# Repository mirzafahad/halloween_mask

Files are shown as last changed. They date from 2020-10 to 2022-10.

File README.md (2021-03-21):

# Halloween Mask



:star: Star me on GitHub — it helps!

Added the famous [Uncanny Eyes](https://learn.adafruit.com/animated-electronic-eyes) to a Mask. The PCB has three connectors for sensors:
- PIR conenctor
- I2C connector for any I2C capabale sensor
- LDR 

If you don't need want to use EL wire you can use the EL wire conenctor for other sensors, motors, relays etc.

Components used:
- [Adafruit ItsyBitsy M0](https://www.adafruit.com/product/3727)
- 2 x 1.44" [TFT Display](https://tinyurl.com/y4xz52jo)
- [Mask](https://tinyurl.com/y5uo26v6)
- [LDR](https://www.adafruit.com/product/161) 

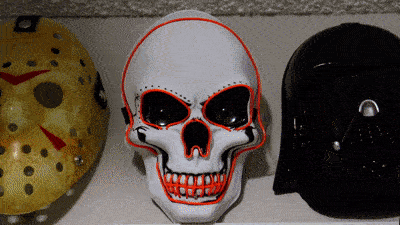
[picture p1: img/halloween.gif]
Mask in action


More info: https://mirzafahad.github.io/2020-10-31-halloween-mask/

Youtube: https://youtu.be/H35RDPNnSZM

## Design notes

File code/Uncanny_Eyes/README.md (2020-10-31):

# Fahad Mirza

Made necessary changes to according to my circuit.

# Uncanny_Eyes

'Uncanny eyes' for Adafruit 1.5" OLED (product #1431) or 1.44" TFT LCD (#2088).  Works on PJRC Teensy 3.x and on Adafruit M0 and M4 boards (Feather, Metro, etc.).  This code uses features specific to these boards and WILL NOT work on normal Arduino or other boards!

How-to guide with parts list and 3D models is here:
https://learn.adafruit.com/animated-electronic-eyes-using-teensy-3-1/overview

Teensy 3.x w/OLED screens: use 72 MHz board speed -- 96 MHz requires throttling back SPI bitrate and actually runs slower!

Directory 'uncannyEyes' contains Arduino sketch for PJRC Teensy 3.1 & Adafruit M0 & M4. 'graphics' subfolder has various eye designs, as #include-able header files.

Folder 'convert' contains Python sketch for generating graphics header files. Requires Python Imaging Library. Example images are also in this directory.

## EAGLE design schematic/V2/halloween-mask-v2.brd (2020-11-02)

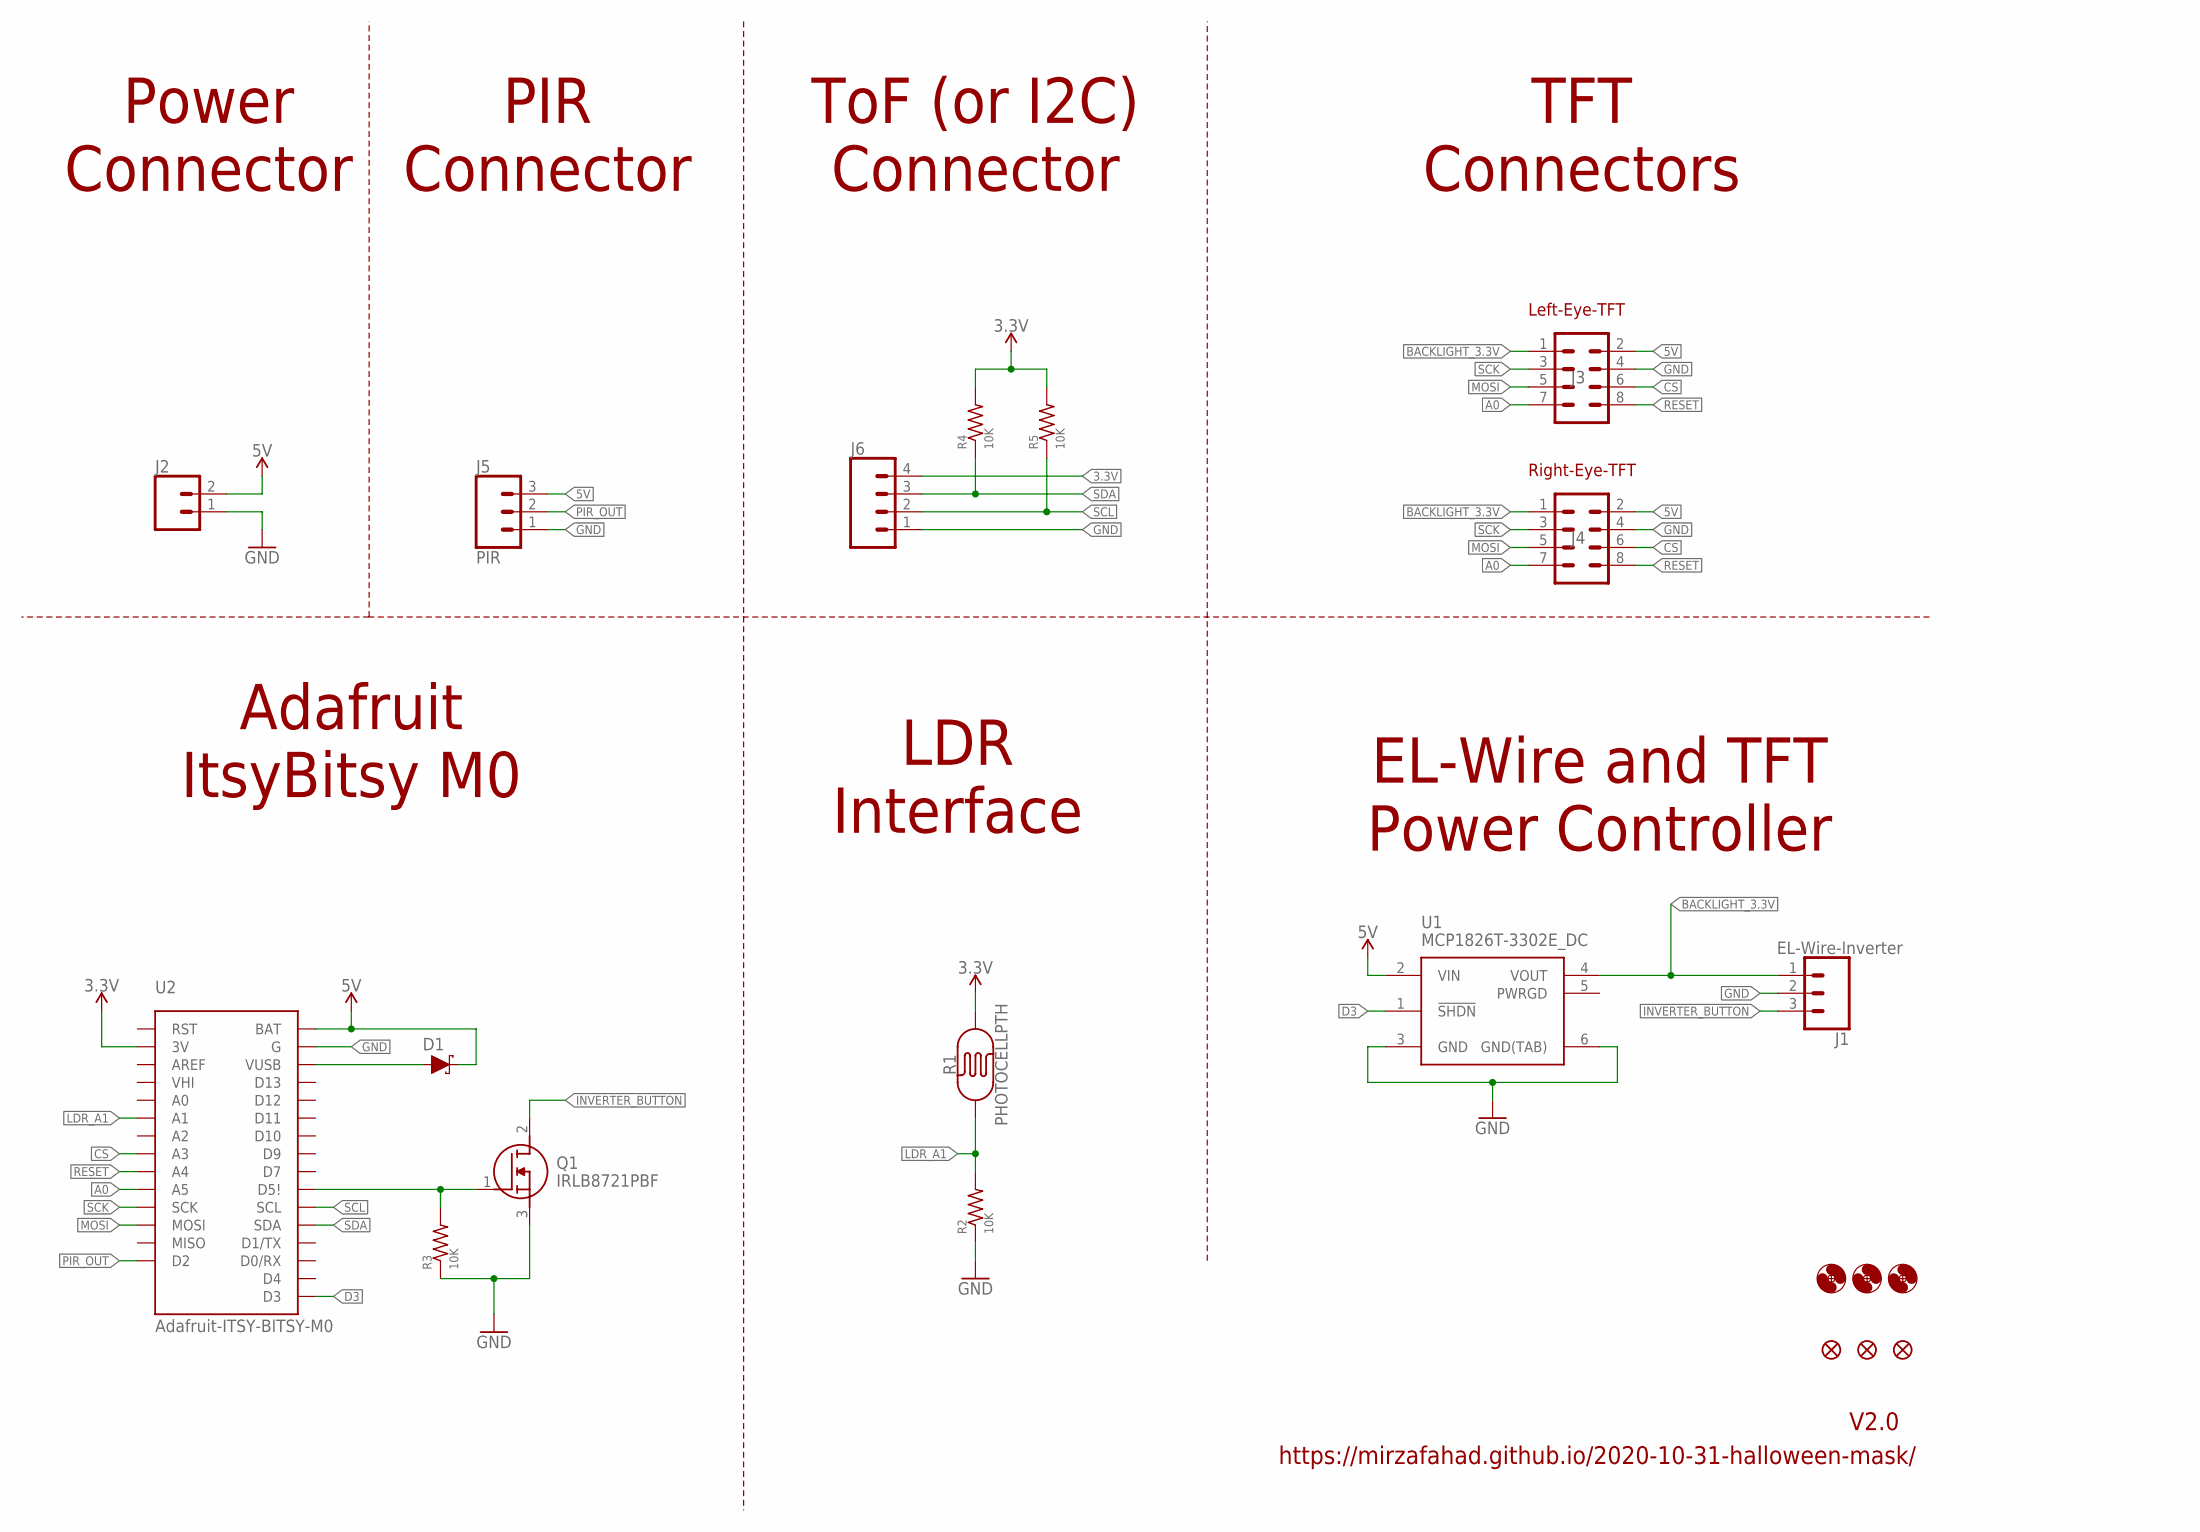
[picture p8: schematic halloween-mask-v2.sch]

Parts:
D1: DIODE-SCHOTTKY-MBR130T1G; SOD-123
FD1, FD2, FD3: FIDUCIAL0.2MM; FIDUCIAL-0.2MM
H1, H2, H4: MOUNT-HOLE2.8; 2,8
J1: EL-Wire-Inverter; 1X03
J2: CONN_02LOCK; 1X02_LOCK
J3, J4: CONN_04X2; 2X4
J5: PIR; 1X03_LOCK
J6: CONN_04PTH; 1X04
Q1: IRLB8721PBF; TO254P483X1016X1994-3P
R1: PHOTOCELLPTH; PHOTOCELL
R2, R3, R4, R5: 10K; R1206
U1: MCP1826T-3302E_DC; SOT127P706X180-6N
U2: Adafruit-ITSY-BITSY-M0; ITSY-BITSY-LESS-PINS

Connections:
3.3V: J6.4, R1.2, R4.2, R5.2, U2.P2 (3V)
5V: D1.2 (C), J2.2, J3.2, J4.2, J5.3, U1.2 (VIN), U2.P28 (BAT)
A0: J3.7, J4.7, U2.P10 (A5)
BACKLIGHT_3.3V: J1.1, J3.1, J4.1, U1.4 (VOUT)
CS: J3.6, J4.6, U2.P8 (A3)
D3: U1.1 (!SHDN), U2.18 (D3)
GND: J1.2, J2.1, J3.4, J4.4, J5.1, J6.1, Q1.3 (S), R2.1, R3.1, U1.3 (GND), U1.6 (GND(TAB)), U2.P27 (G)
INVERTER_BUTTON: J1.3, Q1.2 (D)
LDR_A1: R1.1, R2.2, U2.P6 (A1)
MOSI: J3.5, J4.5, U2.P12 (MOSI)
unnamed: D1.1 (A), U2.P26 (VUSB)
unnamed: Q1.1 (G), R3.2, U2.P19 (D5!)
PIR_OUT: J5.2, U2.P14 (D2)
RESET: J3.8, J4.8, U2.P9 (A4)
SCK: J3.3, J4.3, U2.P11 (SCK)
SCL: J6.2, R5.1, U2.P18 (SCL)
SDA: J6.3, R4.1, U2.P17 (SDA)

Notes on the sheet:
V2.0
TFT Connectors
Left-Eye-TFT
Right-Eye-TFT
ToF (or I2C) Connector
EL-Wire and TFT Power Controller
PIR Connector
Power Connector
LDR Interface
Adafruit ItsyBitsy M0
https://mirzafahad.github.io/2020-10-31-halloween-mask/

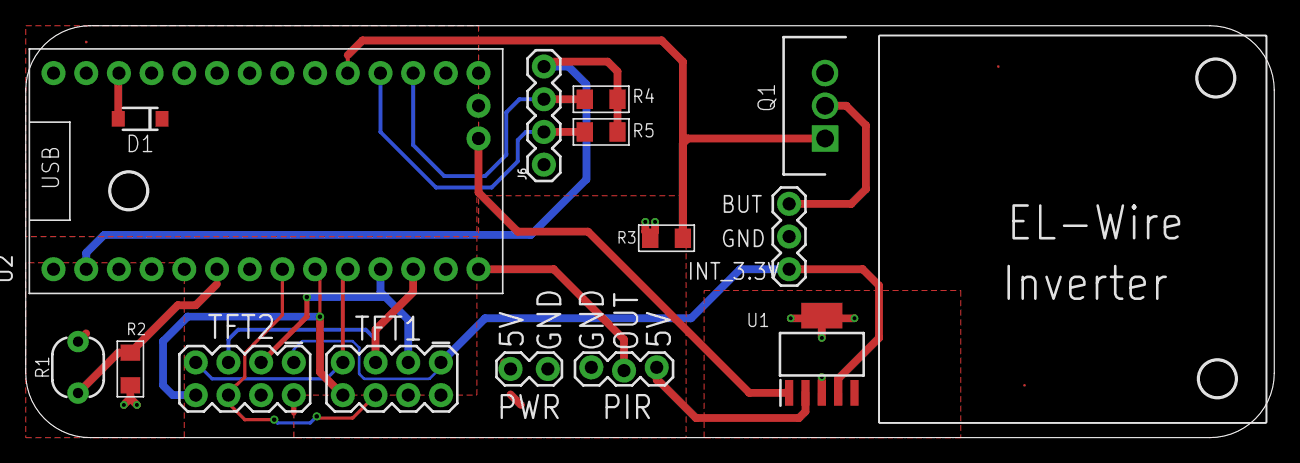
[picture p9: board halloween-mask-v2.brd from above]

Board: 2 copper layers, 97.0 x 32.0 mm, 22 parts (0 on the bottom side), 17 nets.

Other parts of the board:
U$2: ELECTROCAT_LOGO_38X14MM

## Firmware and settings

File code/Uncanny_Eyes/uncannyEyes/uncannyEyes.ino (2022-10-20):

//--------------------------------------------------------------------------
// Uncanny eyes for Adafruit 1.5" OLED (product #1431) or 1.44" TFT LCD
// (#2088).  Works on PJRC Teensy 3.x and on Adafruit M0 and M4 boards
// (Feather, Metro, etc.).  This code uses features specific to these
// boards and WILL NOT work on normal Arduino or other boards!
//
// SEE FILE "config.h" FOR MOST CONFIGURATION (graphics, pins, display type,
// etc).  Probably won't need to edit THIS file unless you're doing some
// extremely custom modifications.
//
// Adafruit invests time and resources providing this open source code,
// please support Adafruit and open-source hardware by purchasing products
// from Adafruit!
//
// Written by Phil Burgess / Paint Your Dragon for Adafruit Industries.
// MIT license.  SPI FIFO insight from Paul Stoffregen's ILI9341_t3 library.
// Inspired by David Boccabella's (Marcwolf) hybrid servo/OLED eye concept.
//--------------------------------------------------------------------------

#include <SPI.h>
#include <Adafruit_GFX.h>
#ifdef ARDUINO_ARCH_SAMD
  #include <Adafruit_ZeroDMA.h>
#endif


typedef struct {        // Struct is defined before including config.h --
  int8_t  select;       // pin numbers for each eye's screen select line
  int8_t  wink;         // and wink button (or -1 if none) specified there,
  uint8_t rotation;     // also display rotation.
} eyeInfo_t;

#include "config.h"     // ****** CONFIGURATION IS DONE IN HERE ******

extern void user_setup(void); // Functions in the user*.cpp files
extern void user_loop(void);

#ifdef PIXEL_DOUBLE
  // For the 240x240 TFT, pixels are rendered in 2x2 blocks for an
  // effective resolution of 120x120. M0 boards just don't have the
  // space or speed to handle an eye at the full resolution of this
  // display (and for M4 boards, take a look at the M4_Eyes project
  // instead). 120x120 doesn't quite match the resolution of the
  // TFT & OLED this project was originally developed for. Rather
  // than make an entirely new alternate set of graphics for every
  // eye (would be a huge undertaking), this currently just crops
  // four pixels all around the perimeter.
  #define SCREEN_X_START 4
  #define SCREEN_X_END   (SCREEN_WIDTH - 4)
  #define SCREEN_Y_START 4
  #define SCREEN_Y_END   (SCREEN_HEIGHT - 4)
#else
  #define SCREEN_X_START 0
  #define SCREEN_X_END   SCREEN_WIDTH
  #define SCREEN_Y_START 0
  #define SCREEN_Y_END   SCREEN_HEIGHT
#endif

#if defined(_ADAFRUIT_ST7789H_)
  typedef Adafruit_ST7789  displayType; // Using 240x240 TFT display(s)
#elif defined(_ADAFRUIT_ST7735H_) || defined(_ADAFRUIT_ST77XXH_)
  //typedef Adafruit_ST7735  displayType; // Using TFT display(s)
  //typedef Adafruit_HX8357  displayType;
  typedef Adafruit_ILI9341 displayType;
#else
  //typedef Adafruit_SSD1351 displayType; // Using OLED display(s)
  //typedef Adafruit_HX8357  displayType;
  typedef Adafruit_ILI9341 displayType;
#endif

// A simple state machine is used to control eye blinks/winks:
#define NOBLINK 0       // Not currently engaged in a blink
#define ENBLINK 1       // Eyelid is currently closing
#define DEBLINK 2       // Eyelid is currently opening
typedef struct 
{
  uint8_t  state;       // NOBLINK/ENBLINK/DEBLINK
  uint32_t duration;    // Duration of blink state (micros)
  uint32_t startTime;   // Time (micros) of last state change
} eyeBlink;

#define NUM_EYES (sizeof eyeInfo / sizeof eyeInfo[0]) // config.h pin list

struct {                // One-per-eye structure
  displayType *display; // -> OLED/TFT object
  eyeBlink     blink;   // Current blink/wink state
} eye[NUM_EYES];

#ifdef ARDUINO_ARCH_SAMD
  // SAMD boards use DMA (Teensy uses SPI FIFO instead):
  // Two single-scanline pixel buffers are used for DMA,
  // alternating rendering and transferring between them.
  // Though you'd think fewer larger transfers would improve speed,
  // multi-line buffering made no appreciable difference.
  uint8_t           dmaIdx = 0; // Active DMA buffer # (alternate fill/send)
  Adafruit_ZeroDMA  dma;
 #ifdef PIXEL_DOUBLE
  uint32_t          dmaBuf[2][120]; // Two 120-pixel buffers (32bit for doubling)
  DmacDescriptor   *descriptor[2];  // Pair of descriptors for doubled scanlines
 #else
  uint16_t          dmaBuf[2][128]; // Two 128-pixel buffers
  DmacDescriptor   *descriptor;     // Single active DMA descriptor
 #endif
  // DMA transfer-in-progress indicator and callback
  static volatile bool dma_busy = false;
  static void dma_callback(Adafruit_ZeroDMA *dma) { dma_busy = false; }
#elif defined(ARDUINO_ARCH_NRF52)
  uint8_t           dmaIdx = 0; // Active DMA buffer # (alternate fill/send)
 #ifdef PIXEL_DOUBLE
  uint32_t          dmaBuf[2][240]; // Two 240-pixel buffers (32bit for doubling)
 #else
  uint16_t          dmaBuf[2][128]; // Two 128-pixel buffers
 #endif
#endif

uint32_t startTime;  // For FPS indicator

#if defined(SYNCPIN) && (SYNCPIN >= 0)
#include <Wire.h>
// If two boards are synchronized over I2C, this struct is passed from one
// to other. No device-independent packing & unpacking is performed...both
// boards are expected to be the same architecture & endianism.
struct {
  uint16_t iScale;  // These are basically the same arguments as
  uint8_t  scleraX; // drawEye() expects, explained in that function.
  uint8_t  scleraY;
  uint8_t  uT;
  uint8_t  lT;
} syncStruct = { 512,
  (SCLERA_WIDTH-SCREEN_WIDTH)/2, (SCLERA_HEIGHT-SCREEN_HEIGHT)/2, 0, 0 };

void wireCallback(int n) {
  if(n == sizeof syncStruct) {
    // Read 'n' bytes from I2C into syncStruct
    uint8_t *ptr = (uint8_t *)&syncStruct;
    for(uint8_t i=0; i < sizeof syncStruct; i++) {
      ptr[i] = Wire.read();
    }
  }
}

bool receiver = false;
#endif // SYNCPIN

// INITIALIZATION -- runs once at startup ----------------------------------

void setup(void) 
{
  uint8_t e; // Eye index, 0 to NUM_EYES-1

#if defined(SYNCPIN) && (SYNCPIN >= 0) // If using I2C sync...
  pinMode(SYNCPIN, INPUT_PULLUP);      // Check for jumper to ground
  if(!digitalRead(SYNCPIN)) {          // If there...
    receiver = true;                   // Set this one up as receiver
    Wire.begin(SYNCADDR);
    Wire.onReceive(wireCallback);
  } else {
    Wire.begin();                      // Else set up as sender
  }
#endif

  Serial.begin(115200);
  //while (!Serial);
  Serial.println("Init");
  randomSeed(analogRead(A0)); // Seed random() from floating analog input

#ifdef DISPLAY_BACKLIGHT
  // Enable backlight pin, initially off
  Serial.println("Backlight off");
  pinMode(DISPLAY_BACKLIGHT, OUTPUT);
  digitalWrite(DISPLAY_BACKLIGHT, LOW);
#endif

  user_setup();

  // Initialize eye objects based on eyeInfo list in config.h:
  for(e=0; e<NUM_EYES; e++) 
  {
    Serial.print("Create display #"); 
    Serial.println(e);
#if defined(_ADAFRUIT_ST7789H_) // 240x240 TFT
    eye[e].display     = new displayType(&TFT_SPI, eyeInfo[e].select, DISPLAY_DC, -1);
#elif defined(_ADAFRUIT_ST7735H_) || defined(_ADAFRUIT_ST77XXH_) // 128x128 TFT
    eye[e].display     = new displayType(&TFT_SPI, eyeInfo[e].select, DISPLAY_DC, -1);
#else // OLED
    //eye[e].display     = new displayType(128, 128, &TFT_SPI, eyeInfo[e].select, DISPLAY_DC, -1);
    // HX8357
    //eye[e].display     = new displayType(&TFT_SPI, eyeInfo[e].select, DISPLAY_DC, DISPLAY_RESET);
    eye[e].display     = new displayType(eyeInfo[e].select, DISPLAY_DC, DISPLAY_RESET);
#endif
    eye[e].blink.state = NOBLINK;
    // If project involves only ONE eye and NO other SPI devices, its
    // select line can be permanently tied to GND and corresponding pin
    // in config.h set to -1.  Best to use it though.
    if(eyeInfo[e].select >= 0) 
    {
      pinMode(eyeInfo[e].select, OUTPUT);
      digitalWrite(eyeInfo[e].select, HIGH); // Deselect them all
    }
    // Also set up an individual eye-wink pin if defined:
    if(eyeInfo[e].wink >= 0) pinMode(eyeInfo[e].wink, INPUT_PULLUP);
  }
#if defined(BLINK_PIN) && (BLINK_PIN >= 0)
  pinMode(BLINK_PIN, INPUT_PULLUP); // Ditto for all-eyes blink pin
#endif

#if defined(DISPLAY_RESET) && (DISPLAY_RESET >= 0)
  // Because both displays share a common reset pin, -1 is passed to
  // the display constructor above to prevent the begin() function from
  // resetting both displays after one is initialized.  Instead, handle
  // the reset manually here to take care of both displays just once:
  Serial.println("Reset displays");
  pinMode(DISPLAY_RESET, OUTPUT);
  digitalWrite(DISPLAY_RESET, LOW);  delay(1);
  digitalWrite(DISPLAY_RESET, HIGH); delay(50);
  // Alternately, all display reset pin(s) could be connected to the
  // microcontroller reset, in which case DISPLAY_RESET should be set
  // to -1 or left undefined in config.h.
#else
  // If no DISPLAY_RESET pin is defined, the board might have an auto-
  // reset circuit for the display (e.g. TFT Gizmo). Pause for just a
  // tiny moment to allow it to work, otherwise commands will be issued
  // too soon and the display won't correctly initialize.
  delay(75);
#endif

  // After all-displays reset, now call init/begin func for each display:
  for(e=0; e<NUM_EYES; e++) {
#if defined(_ADAFRUIT_ST7789H_) // 240x240 TFT
    eye[e].display->init(240, 240);
#elif defined(_ADAFRUIT_ST7735H_) || defined(_ADAFRUIT_ST77XXH_) // 128x128 TFT
    eye[e].display->initR(INITR_144GREENTAB);
    Serial.print("Init ST77xx display #"); Serial.println(e);
#else // OLED
    eye[e].display->begin(SPI_FREQ);
    eye[e].display->fillScreen(ILI9341_BLACK);
#endif
    Serial.println("Rotate");
    eye[e].display->setRotation(eyeInfo[e].rotation);
  }
  Serial.println("done");

#if defined(LOGO_TOP_WIDTH) || defined(COLOR_LOGO_WIDTH)
  // I noticed lots of folks getting right/left eyes flipped, or
  // installing upside-down, etc.  Logo split across screens may help:
  int x = eye[0].display->width() * NUM_EYES / 2;
  int y = (eye[0].display->height() - SCREEN_HEIGHT) / 2;
  for(e=0; e<NUM_EYES; e++) { // Another pass, after all screen inits
    eye[e].display->fillScreen(0);
    #ifdef LOGO_TOP_WIDTH
      // Monochrome Adafruit logo is 2 mono bitmaps:
      eye[e].display->drawBitmap(x - LOGO_TOP_WIDTH / 2 - 20,
        y, logo_top, LOGO_TOP_WIDTH, LOGO_TOP_HEIGHT, 0xFFFF);
      eye[e].display->drawBitmap(x - LOGO_BOTTOM_WIDTH/2,
        y + LOGO_TOP_HEIGHT, logo_bottom, LOGO_BOTTOM_WIDTH, LOGO_BOTTOM_HEIGHT,
        0xFFFF);
    #else
      // Color sponsor logo is one RGB bitmap:
      eye[e].display->fillScreen(color_logo[0]);
      eye[e].display->drawRGBBitmap(
        (eye[e].display->width()  - COLOR_LOGO_WIDTH ) / 2,
        (eye[e].display->height() - COLOR_LOGO_HEIGHT) / 2,
        color_logo, COLOR_LOGO_WIDTH, COLOR_LOGO_HEIGHT);
    #endif
    x -= eye[e].display->width();
  }
  // After logo is drawn
  #ifdef DISPLAY_BACKLIGHT
    int i;
    Serial.println("Fade in backlight");
    analogWriteResolution(8);
    for(i=0; i<=BACKLIGHT_MAX; i++) { // Fade logo in
      analogWrite(DISPLAY_BACKLIGHT, i);
      delay(2);
    }
    delay(1400); // Pause for screen layout/orientation
    Serial.println("Fade out backlight");
    for(; i>=0; i--) {
      analogWrite(DISPLAY_BACKLIGHT, i);
      delay(2);
    }
    for(e=0; e<NUM_EYES; e++) { // Clear display(s)
      eye[e].display->fillScreen(0);
    }
    delay(100);
  #else
    delay(2000); // Pause for screen layout/orientation
  #endif // DISPLAY_BACKLIGHT
#endif // LOGO_TOP_WIDTH

  // One of the displays is configured to mirror on the X axis.  Simplifies
  // eyelid handling in the drawEye() function -- no need for distinct
  // L-to-R or R-to-L inner loops.  Just the X coordinate of the iris is
  // then reversed when drawing this eye, so they move the same.  Magic!
#if defined(SYNCPIN) && (SYNCPIN >= 0)
  if(receiver) {
#endif
#if defined(_ADAFRUIT_ST7789H_) // 240x240 TFT
    // MAYBE TODO: HANDLE 240x240 TFT MIRRORING HERE
#elif defined(_ADAFRUIT_ST7735H_) || defined(_ADAFRUIT_ST77XXH_) // TFT
    const uint8_t mirrorTFT[]  = { 0x88, 0x28, 0x48, 0xE8 }; // Mirror+rotate
    eye[0].display->sendCommand(
    #ifdef ST77XX_MADCTL
      ST77XX_MADCTL, // Current TFT lib
    #else
      ST7735_MADCTL, // Older TFT lib
    #endif
      &mirrorTFT[eyeInfo[0].rotation & 3], 1);
  #else // OLED
//    const uint8_t rotateOLED[] = { 0x74, 0x77, 0x66, 0x65 },
//                  mirrorOLED[] = { 0x76, 0x67, 0x64, 0x75 }; // Mirror+rotate
//    // If OLED, loop through ALL eyes and set up remap register
//    // from either mirrorOLED[] (first eye) or rotateOLED[] (others).
//    // The OLED library doesn't normally use the remap reg (TFT does).
//    for(e=0; e<NUM_EYES; e++) {
//      eye[e].display->sendCommand(SSD1351_CMD_SETREMAP, e ?
//        &rotateOLED[eyeInfo[e].rotation & 3] :
//        &mirrorOLED[eyeInfo[e].rotation & 3], 1);
//}
    const uint8_t mirrorTFT[]  = { 0x88, 0x28, 0x48, 0xE8 }; // Mirror+rotate
    //eye[0].display->sendCommand(HX8357_MADCTL, &mirrorTFT[eyeInfo[0].rotation & 3], 1);
    eye[0].display->sendCommand(ILI9341_MADCTL, &mirrorTFT[eyeInfo[0].rotation & 3], 1);
    
#endif
#if defined(SYNCPIN) && (SYNCPIN >= 0)
  } // Don't mirror receiver screen
#endif

#ifdef ARDUINO_ARCH_SAMD
  // Set up SPI DMA on SAMD boards:
  int                dmac_id  = TFT_SPI.getDMAC_ID_TX();
  volatile uint32_t *data_reg = TFT_SPI.getDataRegister();

  Serial.println("DMA init");
  dma.allocate();
  dma.setTrigger(dmac_id);
  dma.setAction(DMA_TRIGGER_ACTON_BEAT);
#ifdef PIXEL_DOUBLE
  // A chain of 2 linked descriptors point to the same buffer.
  // Poof, doubled scanlines.
  for(uint8_t i=0; i<2; i++) {
    descriptor[i] = dma.addDescriptor(
      NULL,               // move data
      (void *)data_reg,   // to here
      sizeof dmaBuf[0],   // this many...
      DMA_BEAT_SIZE_BYTE, // bytes/hword/words
      true,               // increment source addr?
      false);             // increment dest addr?
  }
#else
  descriptor = dma.addDescriptor(
    NULL,               // move data
    (void *)data_reg,   // to here
    sizeof dmaBuf[0],   // this many...
    DMA_BEAT_SIZE_BYTE, // bytes/hword/words
    true,               // increment source addr?
    false);             // increment dest addr?
#endif
  dma.setCallback(dma_callback);

#endif // End SAMD-specific SPI DMA init

#ifdef DISPLAY_BACKLIGHT
  Serial.println("Backlight on!");
  analogWrite(DISPLAY_BACKLIGHT, BACKLIGHT_MAX);
#endif

  startTime = millis(); // For frame-rate calculation
}


// EYE-RENDERING FUNCTION --------------------------------------------------

SPISettings settings(SPI_FREQ, MSBFIRST, SPI_MODE0);

void drawEye( // Renders one eye.  Inputs must be pre-clipped & valid.
  uint8_t  e,       // Eye array index; 0 or 1 for left/right
  uint16_t iScale,  // Scale factor for iris (0-1023)
  uint8_t  scleraX, // First pixel X offset into sclera image
  uint8_t  scleraY, // First pixel Y offset into sclera image
  uint8_t  uT,      // Upper eyelid threshold value
  uint8_t  lT) {    // Lower eyelid threshold value

  uint8_t  screenX, screenY, scleraXsave;
  int16_t  irisX, irisY;
  uint16_t p, a;
  uint32_t d;

#if defined(SYNCPIN) && (SYNCPIN >= 0)
  if(receiver) {
    // Overwrite arguments with values in syncStruct.  Disable interrupts
    // briefly so new data can't overwrite the struct in mid-parse.
    noInterrupts();
    iScale  = syncStruct.iScale;
    // Screen is mirrored, this 'de-mirrors' the eye X direction
    scleraX = SCLERA_WIDTH - 1 - SCREEN_WIDTH - syncStruct.scleraX;
    scleraY = syncStruct.scleraY;
    uT      = syncStruct.uT;
    lT      = syncStruct.lT;
    interrupts();
  } else {
    // Stuff arguments into syncStruct and send to receiver
    syncStruct.iScale  = iScale;
    syncStruct.scleraX = scleraX;
    syncStruct.scleraY = scleraY;
    syncStruct.uT      = uT;
    syncStruct.lT      = lT;
    Wire.beginTransmission(SYNCADDR);
    Wire.write((char *)&syncStruct, sizeof syncStruct);
    Wire.endTransmission();
  }
#endif

#ifdef PIXEL_DOUBLE
  scleraX += 4;
  scleraY += 4;
#endif

  uint8_t  irisThreshold = (128 * (1023 - iScale) + 512) / 1024;
  uint32_t irisScale     = IRIS_MAP_HEIGHT * 65536 / irisThreshold;

  // Set up raw pixel dump to entire screen.  Although such writes can wrap
  // around automatically from end of rect back to beginning, the region is
  // reset on each frame here in case of an SPI glitch.
  TFT_SPI.beginTransaction(settings);
  digitalWrite(eyeInfo[e].select, LOW);                // Chip select

#if defined(_ADAFRUIT_ST7789H_) // 240x240 TFT
  eye[e].display->setAddrWindow(0, 0, 240, 240);
#elif defined(_ADAFRUIT_ST7735H_) || defined(_ADAFRUIT_ST77XXH_) // TFT
  eye[e].display->setAddrWindow(0, 0, 128, 128);
#else // OLED
//  eye[e].display->writeCommand(SSD1351_CMD_SETROW);    // Y range
//  eye[e].display->spiWrite(0); eye[e].display->spiWrite(SCREEN_HEIGHT - 1);
//  eye[e].display->writeCommand(SSD1351_CMD_SETCOLUMN); // X range
//  eye[e].display->spiWrite(0); eye[e].display->spiWrite(SCREEN_WIDTH  - 1);
//  eye[e].display->writeCommand(SSD1351_CMD_WRITERAM);  // Begin write
  eye[e].display->setAddrWindow(40, 0, 240, 320);
#endif
  digitalWrite(eyeInfo[e].select, LOW);                // Re-chip-select
  digitalWrite(DISPLAY_DC, HIGH);                      // Data mode
  // Now just issue raw 16-bit values for every pixel...
  scleraXsave = scleraX + SCREEN_X_START; // Save initial X value to reset on each line
  irisY       = scleraY - (SCLERA_HEIGHT - IRIS_HEIGHT) / 2;
  for(screenY=SCREEN_Y_START; screenY<SCREEN_Y_END; screenY++, scleraY++, irisY++) {
#if defined(ARDUINO_ARCH_SAMD) || defined(ARDUINO_ARCH_NRF52)
 #ifdef PIXEL_DOUBLE
    uint32_t *ptr = &dmaBuf[dmaIdx][0];
 #else
    uint16_t *ptr = &dmaBuf[dmaIdx][0];
 #endif
#endif
    scleraX = scleraXsave;
    irisX   = scleraXsave - (SCLERA_WIDTH - IRIS_WIDTH) / 2;
    for(screenX=SCREEN_X_START; screenX<SCREEN_X_END; screenX++, scleraX++, irisX++) {
      if((lower[screenY][screenX] <= lT) ||
         (upper[screenY][screenX] <= uT)) {             // Covered by eyelid
        p = 0;
      } else if((irisY < 0) || (irisY >= IRIS_HEIGHT) ||
                (irisX < 0) || (irisX >= IRIS_WIDTH)) { // In sclera
        p = sclera[scleraY][scleraX];
      } else {                                          // Maybe iris...
        p = polar[irisY][irisX];                        // Polar angle/dist
        d = p & 0x7F;                                   // Distance from edge (0-127)
        if(d < irisThreshold) {                         // Within scaled iris area
          d = d * irisScale / 65536;                    // d scaled to iris image height
          a = (IRIS_MAP_WIDTH * (p >> 7)) / 512;        // Angle (X)
          p = iris[d][a];                               // Pixel = iris
        } else {                                        // Not in iris
          p = sclera[scleraY][scleraX];                 // Pixel = sclera
        }
      }
#if defined(ARDUINO_ARCH_SAMD) || defined(ARDUINO_ARCH_NRF52)
 #ifdef PIXEL_DOUBLE
      // Swap bytes, duplicate low 16 to high 16 bits, store in DMA buf
      *ptr++ = __builtin_bswap16(p) * 0x00010001;
 #else
      *ptr++ = __builtin_bswap16(p); // DMA: store in scanline buffer
 #endif
#else
      // SPI FIFO technique from Paul Stoffregen's ILI9341_t3 library:
      while(KINETISK_SPI0.SR & 0xC000); // Wait for space in FIFO
      KINETISK_SPI0.PUSHR = p | SPI_PUSHR_CTAS(1) | SPI_PUSHR_CONT;
#endif
    } // end column
#ifdef ARDUINO_ARCH_SAMD
    while(dma_busy); // Wait for prior DMA xfer to finish
 #ifdef PIXEL_DOUBLE
    descriptor[0]->SRCADDR.reg = descriptor[1]->SRCADDR.reg =
      (uint32_t)&dmaBuf[dmaIdx] + sizeof dmaBuf[0];
 #else
    descriptor->SRCADDR.reg = (uint32_t)&dmaBuf[dmaIdx] + sizeof dmaBuf[0];
 #endif
    dma_busy = true;
    dmaIdx   = 1 - dmaIdx;
    dma.startJob();
#elif defined(ARDUINO_ARCH_NRF52)
 #ifdef PIXEL_DOUBLE
    // On nRF52, copy scanline so a single writePixels() call can be used.
    // At present, this is a few FPS slower than two writePixels() calls
    // of the same data, but the idea is that writePixels() could be
    // updated on nRF52 to allow non-blocking DMA transfers (while it does
    // use DMA for the transfer and avoids inter-byte delays, it currently
    // always blocks and can't use that transfer time for other tasks, as
    // the SAMD code does). Should get a sizable boost from that, so it's
    // written here with that in mind for the future...
    uint16_t *base = (uint16_t *)&dmaBuf[dmaIdx];
    memcpy(&base[240], base, 480);
 #endif
    // Block on last scanline
    eye[e].display->writePixels((uint16_t *)&dmaBuf[dmaIdx], sizeof dmaBuf[0] / 2, (screenY == (SCREEN_Y_END-1)), true);
    dmaIdx = 1 - dmaIdx;
#endif
  } // end scanline
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
void loop() {

#if defined(LIGHT_PIN) && (LIGHT_PIN >= 0) // Interactive iris

  int16_t v = analogRead(LIGHT_PIN);       // Raw dial/photocell reading
#ifdef LIGHT_PIN_FLIP
  v = 1023 - v;                            // Reverse reading from sensor
#endif
  if(v < LIGHT_MIN)      v = LIGHT_MIN;  // Clamp light sensor range
  else if(v > LIGHT_MAX) v = LIGHT_MAX;
  v -= LIGHT_MIN;  // 0 to (LIGHT_MAX - LIGHT_MIN)
#ifdef LIGHT_CURVE  // Apply gamma curve to sensor input?
  v = (int16_t)(pow((double)v / (double)(LIGHT_MAX - LIGHT_MIN),
    LIGHT_CURVE) * (double)(LIGHT_MAX - LIGHT_MIN));
#endif
  // And scale to iris range (IRIS_MAX is size at LIGHT_MIN)
  v = map(v, 0, (LIGHT_MAX - LIGHT_MIN), IRIS_MAX, IRIS_MIN);
#ifdef IRIS_SMOOTH // Filter input (gradual motion)
  static int16_t irisValue = (IRIS_MIN + IRIS_MAX) / 2;
  irisValue = ((irisValue * 15) + v) / 16;
  frame(irisValue);
#else // Unfiltered (immediate motion)
  frame(v);
#endif // IRIS_SMOOTH

#else  // Autonomous iris scaling -- invoke recursive function

  newIris = random(IRIS_MIN, IRIS_MAX);
  split(oldIris, newIris, micros(), 10000000L, IRIS_MAX - IRIS_MIN);
  oldIris = newIris;

#endif // LIGHT_PIN
}

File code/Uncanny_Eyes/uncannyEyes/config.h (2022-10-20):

// Pin selections here are based on the original Adafruit Learning System
// guide for the Teensy 3.x project.  Some of these pin numbers don't even
// exist on the smaller SAMD M0 & M4 boards, so you may need to make other
// selections:

// GRAPHICS SETTINGS (appearance of eye) -----------------------------------

// If using a SINGLE EYE, you might want this next line enabled, which
// uses a simpler "football-shaped" eye that's left/right symmetrical.
// Default shape includes the caruncle, creating distinct left/right eyes.
// Hallowing, with one eye, does this by default
#if defined(ADAFRUIT_HALLOWING) || defined(ARDUINO_SAMD_CIRCUITPLAYGROUND_EXPRESS) || defined(ARDUINO_NRF52840_CIRCUITPLAY)
  #define SYMMETRICAL_EYELID
#else                     // Otherwise your choice, standard is asymmetrical
  #define SYMMETRICAL_EYELID
#endif

#define PIXEL_DOUBLE

// Enable ONE of these #includes -- HUGE graphics tables for various eyes:
//#include "graphics/defaultEye.h"      // Standard human-ish hazel eye -OR-
#include "graphics/dragonEye.h"     // Slit pupil fiery dragon/demon eye -OR-
//#include "graphics/noScleraEye.h"   // Large iris, no sclera -OR-
//#include "graphics/goatEye.h"       // Horizontal pupil goat/Krampus eye -OR-
//#include "graphics/newtEye.h"       // Eye of newt -OR-
//#include "graphics/terminatorEye.h" // Git to da choppah!
//#include "graphics/catEye.h"        // Cartoonish cat (flat "2D" colors)
//#include "graphics/owlEye.h"        // Minerva the owl (DISABLE TRACKING)
//#include "graphics/naugaEye.h"      // Nauga googly eye (DISABLE TRACKING)
//#include "graphics/doeEye.h"        // Cartoon deer eye (DISABLE TRACKING)

// Optional: enable this line for startup logo (screen test/orient):
#if !defined(ADAFRUIT_HALLOWING)    // Hallowing can't always fit logo+eye
//  #include "graphics/logo.h"        // Otherwise your choice, if it fits
#endif

// EYE LIST ----------------------------------------------------------------

// This table contains ONE LINE PER EYE.  The table MUST be present with
// this name and contain ONE OR MORE lines.  Each line contains THREE items:
// a pin number for the corresponding TFT/OLED display's SELECT line, a pin
// pin number for that eye's "wink" button (or -1 if not used), and a screen
// rotation value (0-3) for that eye.

eyeInfo_t eyeInfo[] = {
#if defined(ADAFRUIT_HALLOWING)
  { 39, -1, 2 }, // SINGLE EYE display-select and wink pins, rotate 180
#elif defined(ARDUINO_SAMD_CIRCUITPLAYGROUND_EXPRESS) || defined(ARDUINO_NRF52840_CIRCUITPLAY)
  { A6, -1, 2 }, // SINGLE EYE display-select and wink pins, rotate 180
#elif defined(ADAFRUIT_TRINKET_M0)
  {  0, -1, 0 }, // SINGLE EYE display-select, no wink, no rotation
#else
  //{ A1, 2, 2 }, // LEFT EYE display-select and wink pins, no rotation
  { A3, -1, 1 }, // RIGHT EYE display-select and wink pins, no rotation
#endif
};

// DISPLAY HARDWARE SETTINGS (screen type & connections) -------------------

#if defined(ARDUINO_SAMD_CIRCUITPLAYGROUND_EXPRESS)
  #define TFT_SPI        SPI1
  #define TFT_PERIPH     PERIPH_SPI1
#else
  #define TFT_SPI        SPI
  #define TFT_PERIPH     PERIPH_SPI
#endif

#if defined(ADAFRUIT_HALLOWING)
  #include <Adafruit_ST7735.h>  // 128x128 TFT display library
  #define DISPLAY_DC        38  // Display data/command pin
  #define DISPLAY_RESET     37  // Display reset pin
  #define DISPLAY_BACKLIGHT  7
  #define BACKLIGHT_MAX    128
  //#define SYNCPIN         A2  // I2C sync if set, GND this pin on receiver
  //#define SYNCADDR      0x08  // I2C address of receiver
                                // (Try disabling SYMMETRICAL_EYELID then)
#elif defined(ARDUINO_SAMD_CIRCUITPLAYGROUND_EXPRESS) || defined(ARDUINO_NRF52840_CIRCUITPLAY)
  #include <Adafruit_ST7789.h> // 240x240 TFT display library
  #define DISPLAY_DC        A7 // Display data/command pin
  #define DISPLAY_RESET     -1 // Display reset pin
  #define DISPLAY_BACKLIGHT A3
  #define BACKLIGHT_MAX    255
#else
  // Enable ONE of these #includes to specify the display type being used
  //#include <Adafruit_SSD1351.h>  // OLED display library -OR-
  //#include <Adafruit_ST7735.h>  // TFT display library (enable one only)
  //#include "Adafruit_HX8357.h"
  #include "Adafruit_ILI9341.h"
  #if defined(ADAFRUIT_TRINKET_M0)
    #define DISPLAY_DC       1
    #define DISPLAY_RESET   -1 // Use MCU reset pin
  #else
    #define DISPLAY_DC       A5  // Data/command pin for ALL displays
    #define DISPLAY_RESET    A4  // Reset pin for ALL displays
  #endif
#endif
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

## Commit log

2020-10-31 Initial commit.
    [halloween-mask-v2.brd, halloween-mask-v2.sch]
2020-10-31 Made necessary changes according to my circuit.
2020-11-02 Added a connector for ToF. Added a schotky diode from Vusb to Vbat, so that I can both use external power and USB.
    [halloween-mask-v2.brd, halloween-mask-v2.sch]

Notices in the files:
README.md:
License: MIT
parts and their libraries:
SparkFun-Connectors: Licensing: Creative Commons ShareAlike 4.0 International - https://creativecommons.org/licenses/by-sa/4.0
